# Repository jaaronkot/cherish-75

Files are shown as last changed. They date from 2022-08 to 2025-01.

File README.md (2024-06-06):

## Cherish-75

<p align="left">
  <a href="./README.md">English</a> |
  <a href="./README_CN.md">简体中文</a>
</p>

Cherish-75 is a customized mechanical keyboard featuring a Gasket structure, with its PCB already verified through prototyping.

Qmk and via support,[Source Code](https://github.com/qmk/qmk_firmware/tree/master/keyboards/soda/cherish)

## Features
* License: MIT – Free to use and modify.
* Controller: STM32F072CBT6, with a separate Type-C subboard ensuring soft elasticity.
* PCB: Slotted PCB design with optional solder mask opening (gold plating available). See [Link](https://oshwhub.com/caiyahoho/Cherish-75) for the LCSC project.
* Layout: 75% size, Fang tooth arrangement.
* Switch: Supports both soldering and hot-swappable switches.
* RGB: Features an RGB SMD LED beneath the Caps Lock key.
* Firmware: Compatible with QMK & VIA. Refer to the [fireware] directory for details.
* Case: 3D printed design with magnetic top and bottom covers. Check the [3d-model] directory for designs.

## Instructions
Magnet specifications: Diameter 3mm x thickness 2mm, available on TaoBao
Circuit board: 5 pieces, JLCPCB, 110 yuan
Components: Shaft support, chip, around 50 yuan, available on the JLCPCB online store
Positioning board: With or without slots, recommended material is FR4 or POM, 30-40 yuan per sheet, recommended store on TaoBao is "Proud Cat" for high accuracy
Place 2mm thick P foam on each pin of the PCB
3D print the casing, options include JLCPCB's 3D Monkey or Future Factory, 3D Monkey has higher accuracy but slightly higher price, the upper and lower casing would be around 150-200 yuan.

```bash
├── case-and-plate
│   ├── top-case-with-X.stl 
│   ├── top-case.stl
│   ├── bottom-case.stl
│   ├── slotted-plate.dwg
│   └── plate.dxf
├── firmware
│   ├── bin  
│   └── cherish-75-via.json # Via Config
├── hardware
│   ├── bom.xlsx # BOM
│   └── gerber # PCB  Gerber 
```

## PCB
### Black
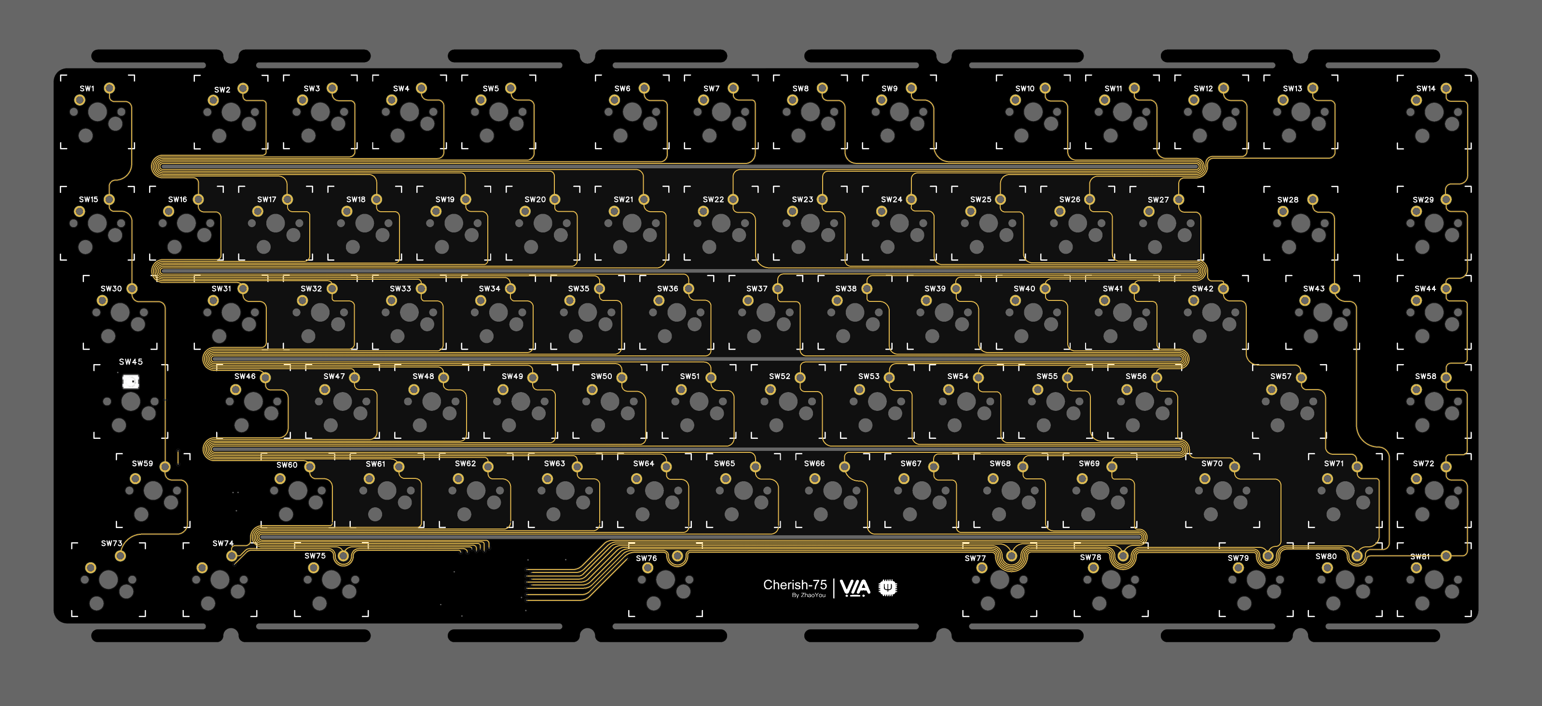
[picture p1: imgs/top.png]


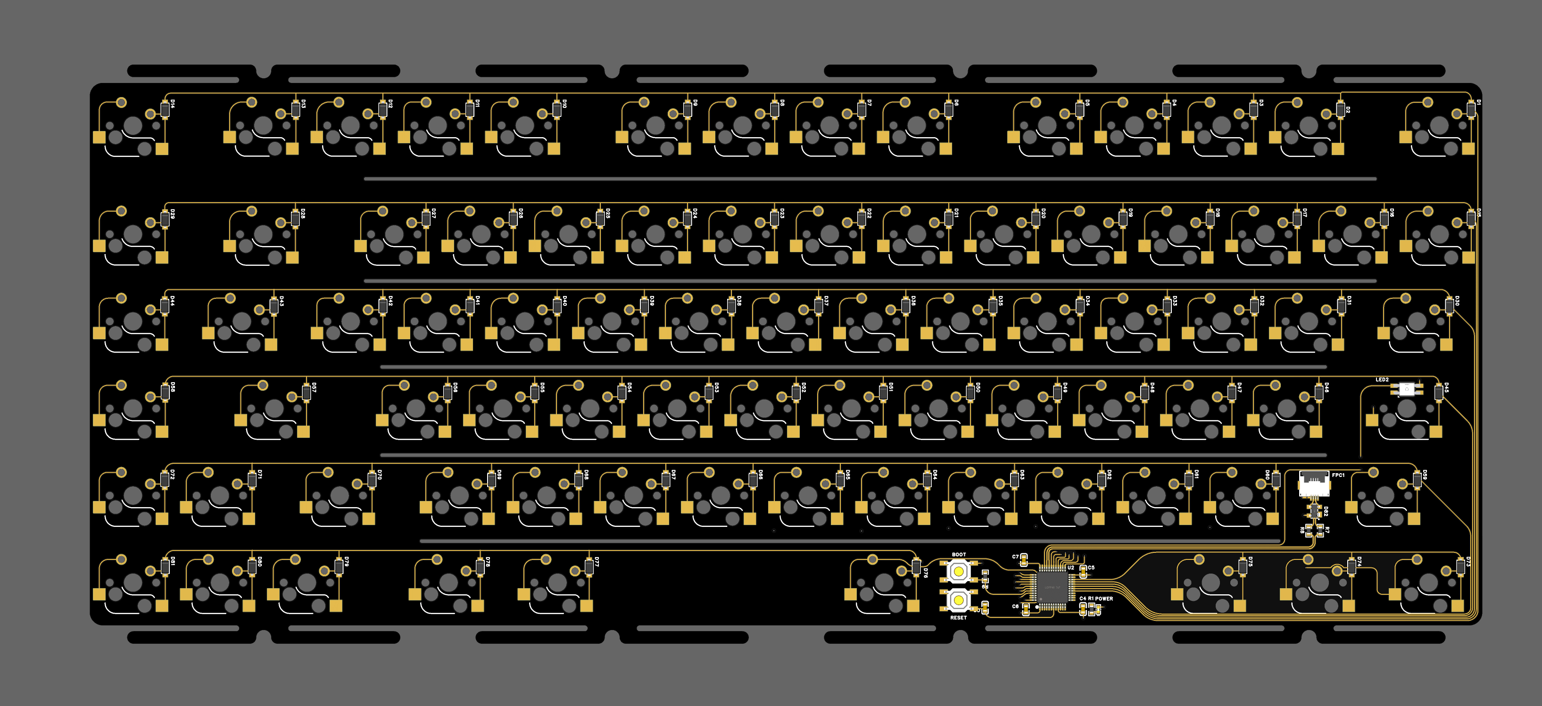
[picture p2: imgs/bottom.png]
bottom


### White:
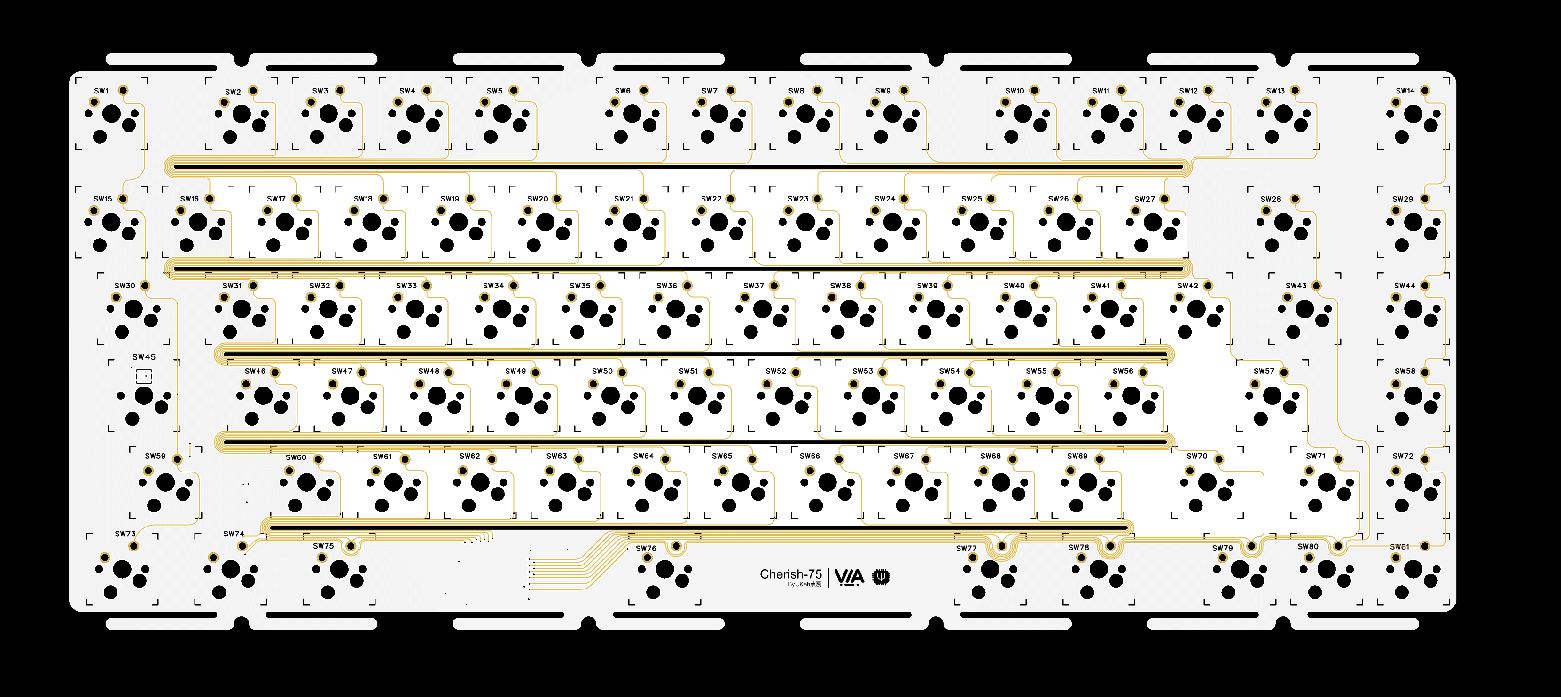
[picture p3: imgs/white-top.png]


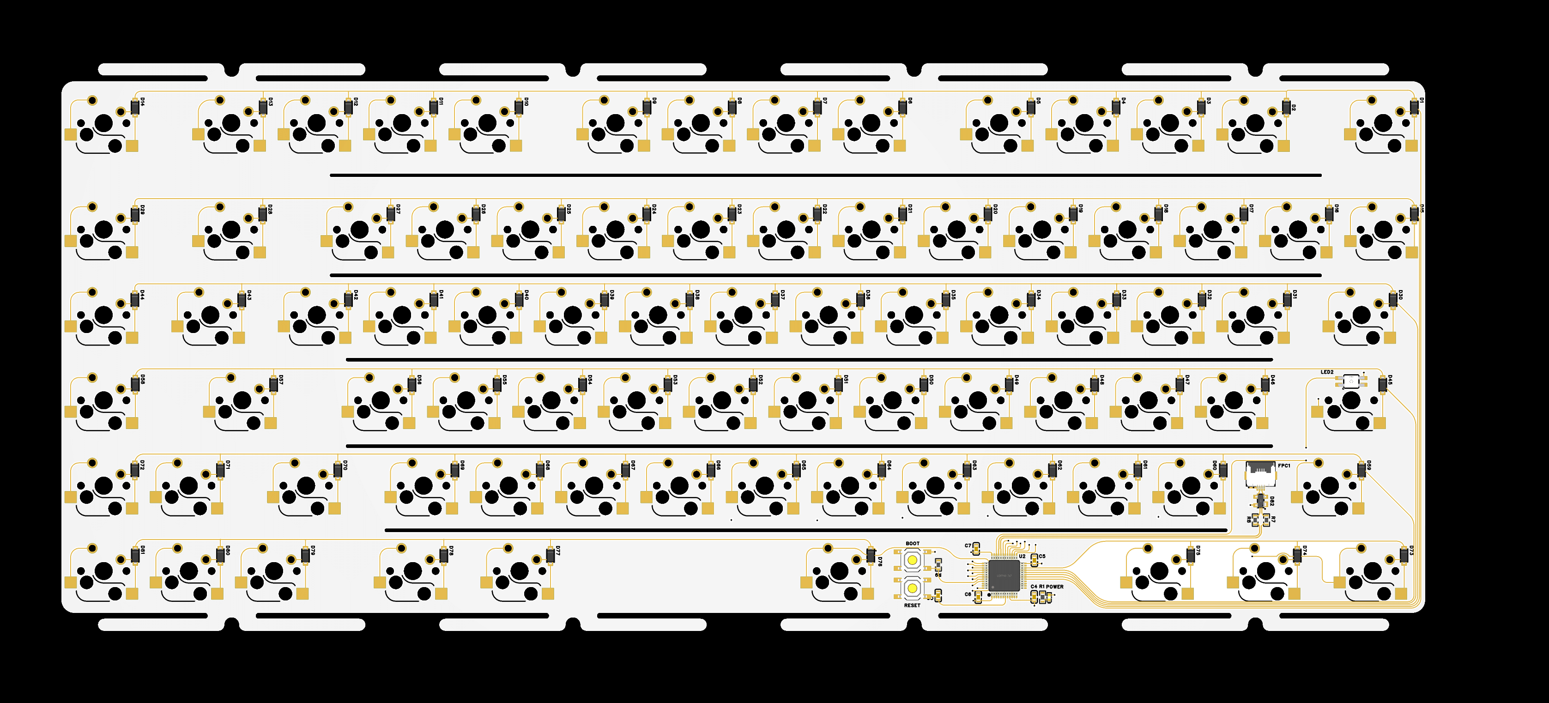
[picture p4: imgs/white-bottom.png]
bottom


### Daughterboard

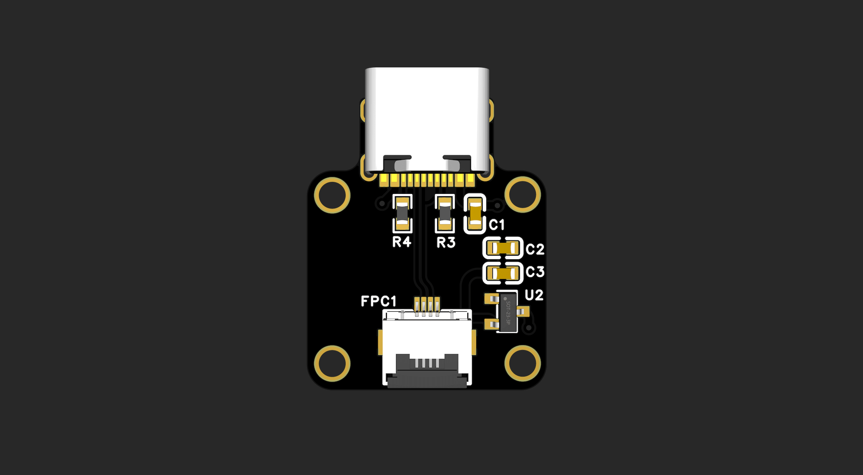
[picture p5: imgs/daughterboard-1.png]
daughterboard


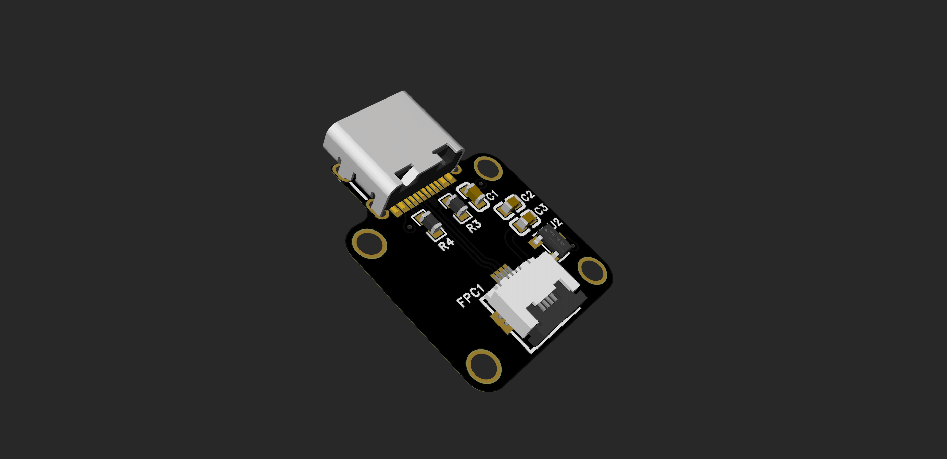
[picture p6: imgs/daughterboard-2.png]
daughterboard


## Layout

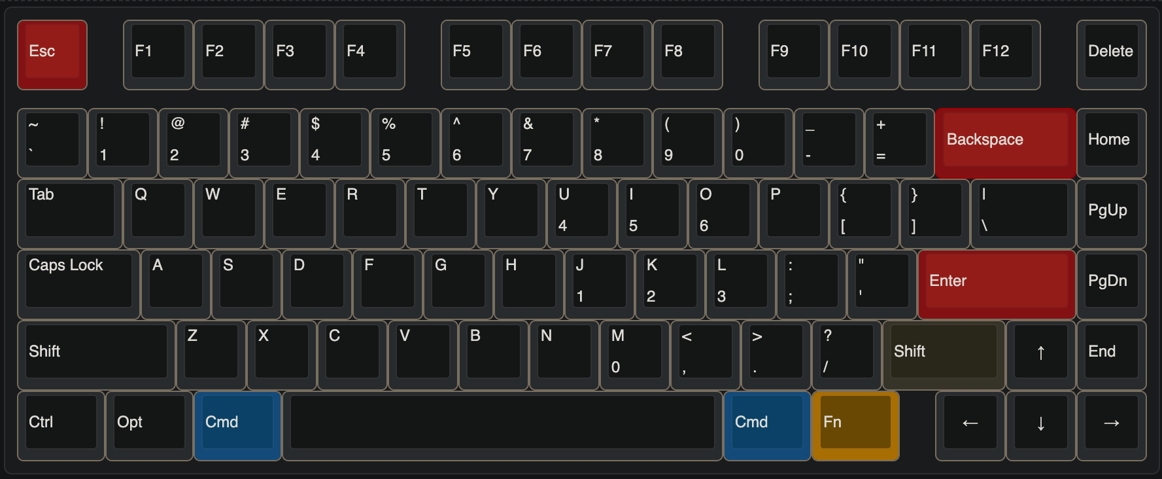
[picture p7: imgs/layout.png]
layout


**Via**
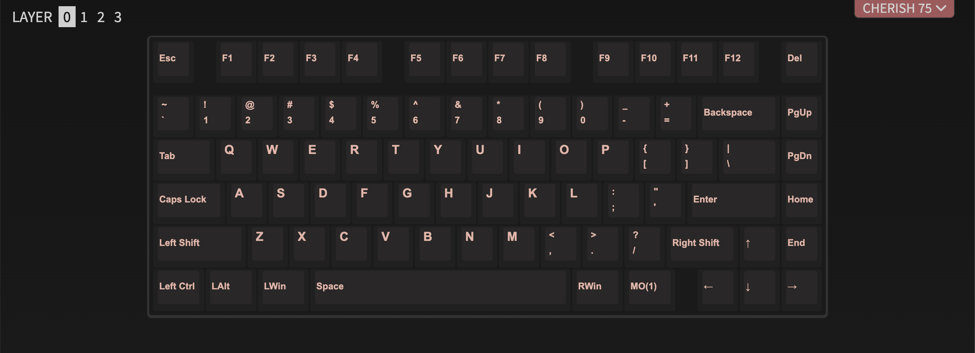
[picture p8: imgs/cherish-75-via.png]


## Case
### Top Case, Style 1

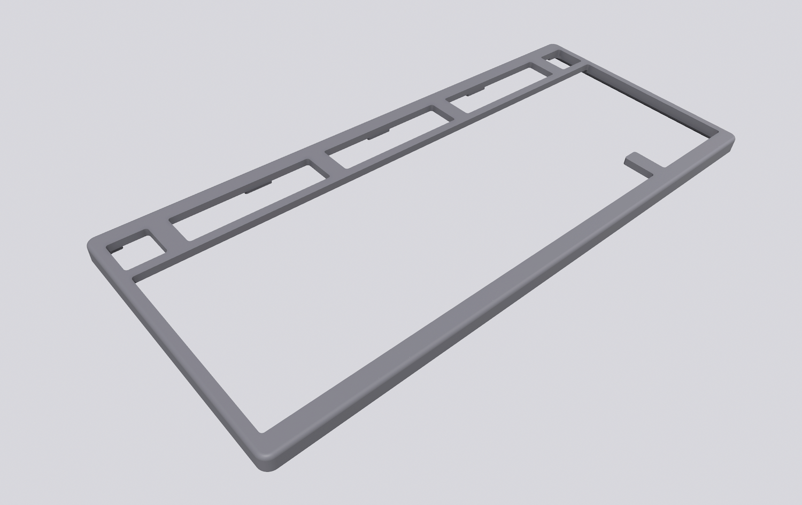
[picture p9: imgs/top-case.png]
top-case


### Top Case, Style 2

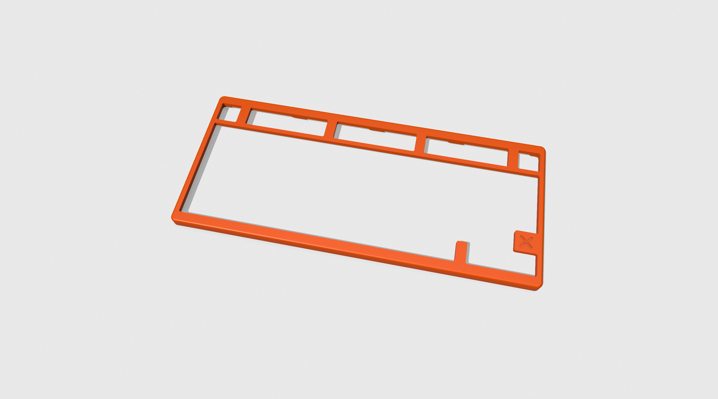
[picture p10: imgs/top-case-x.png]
top-case-x


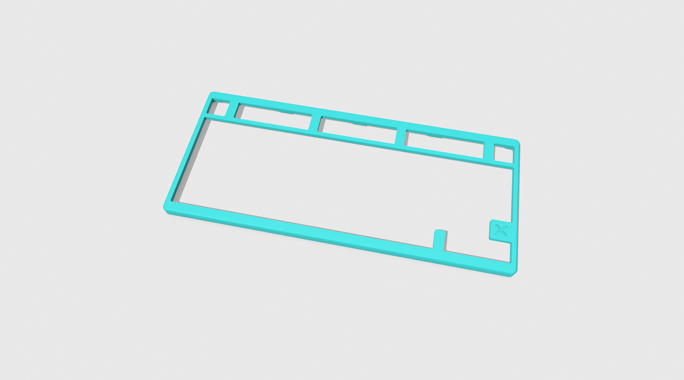
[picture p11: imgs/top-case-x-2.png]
top-case-x


### Overview

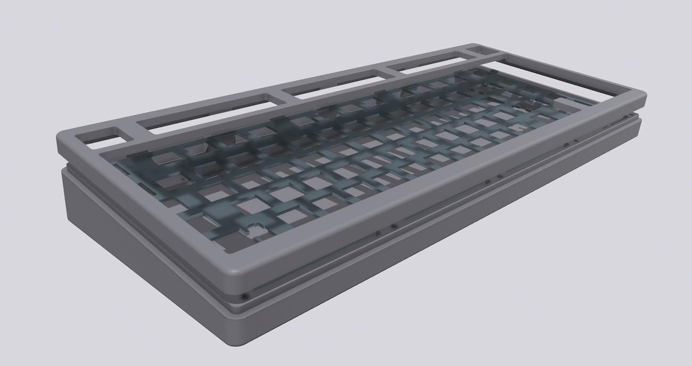
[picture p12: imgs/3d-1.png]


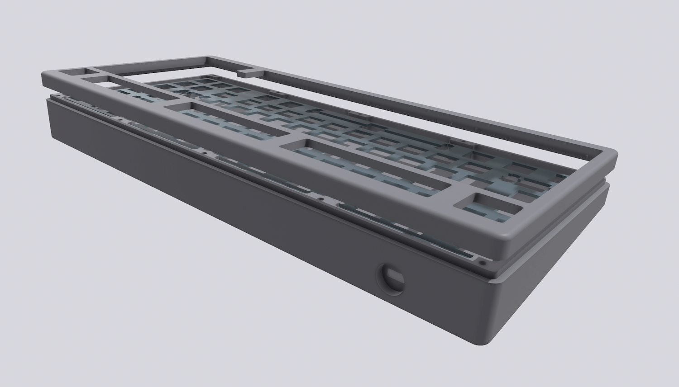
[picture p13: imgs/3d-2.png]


## Physical

### Plate

[plate-1.jpg](imgs/plate-1.jpg)

### PCB 

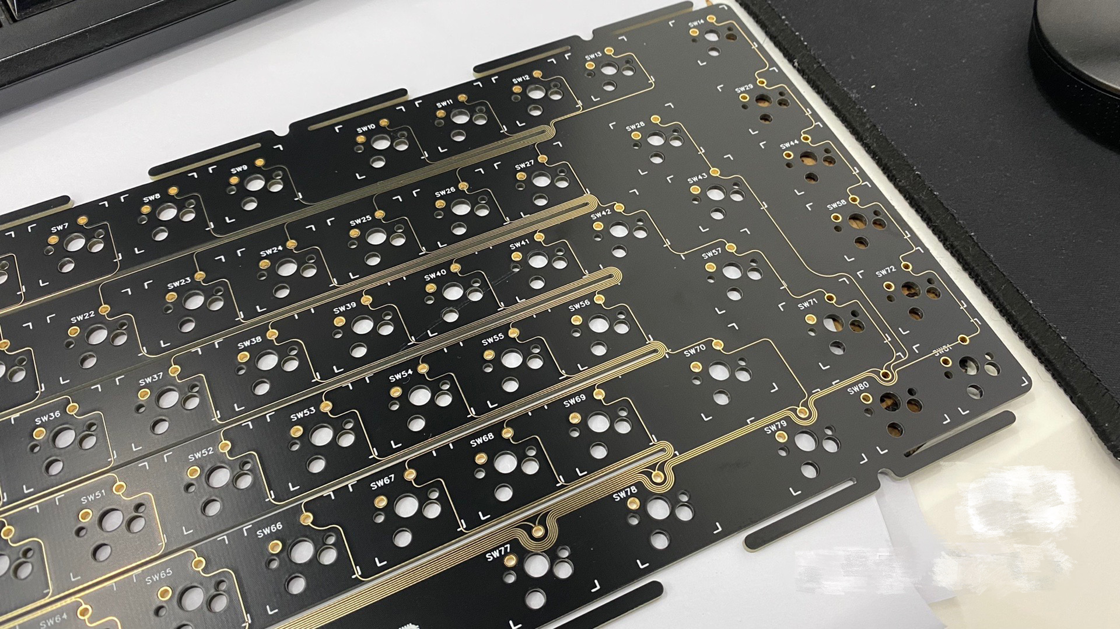
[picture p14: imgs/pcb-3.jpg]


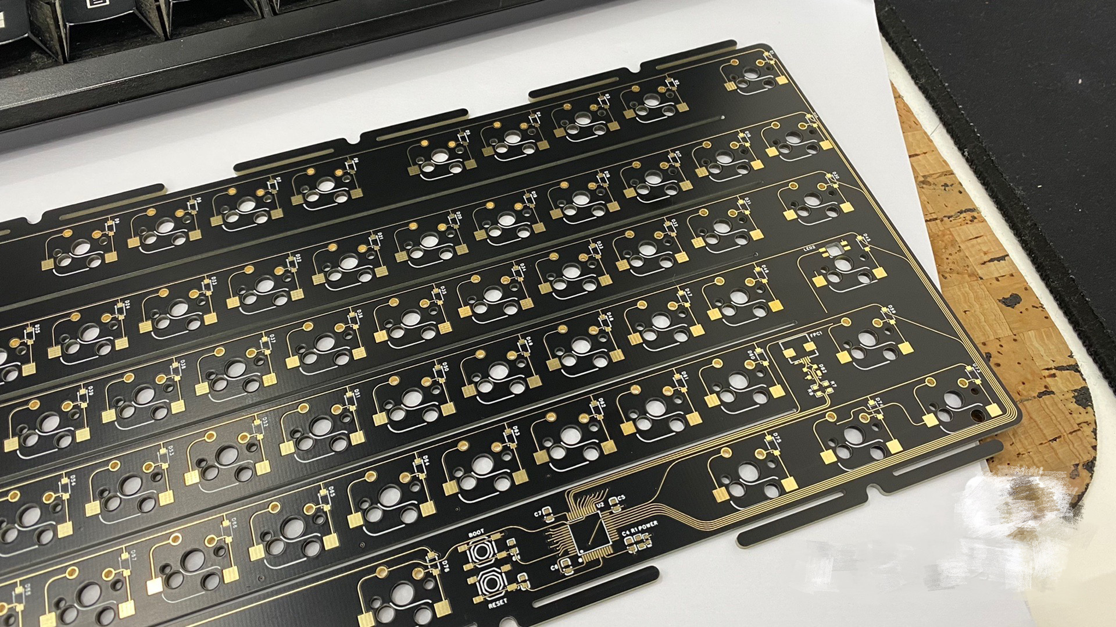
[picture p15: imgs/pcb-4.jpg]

 
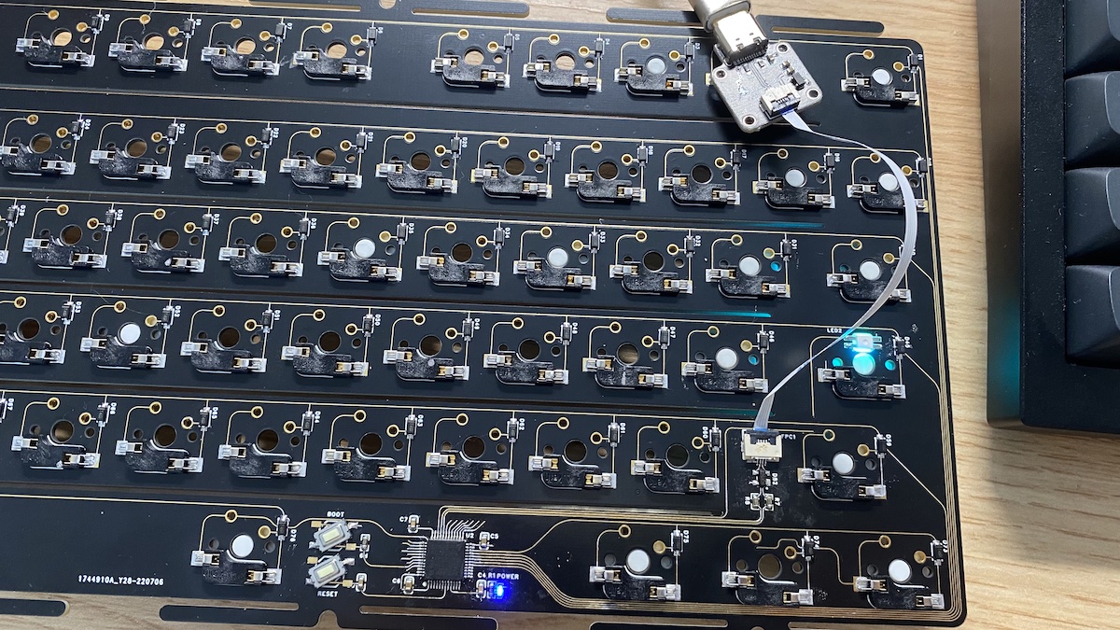
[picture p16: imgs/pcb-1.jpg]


### Keyboard
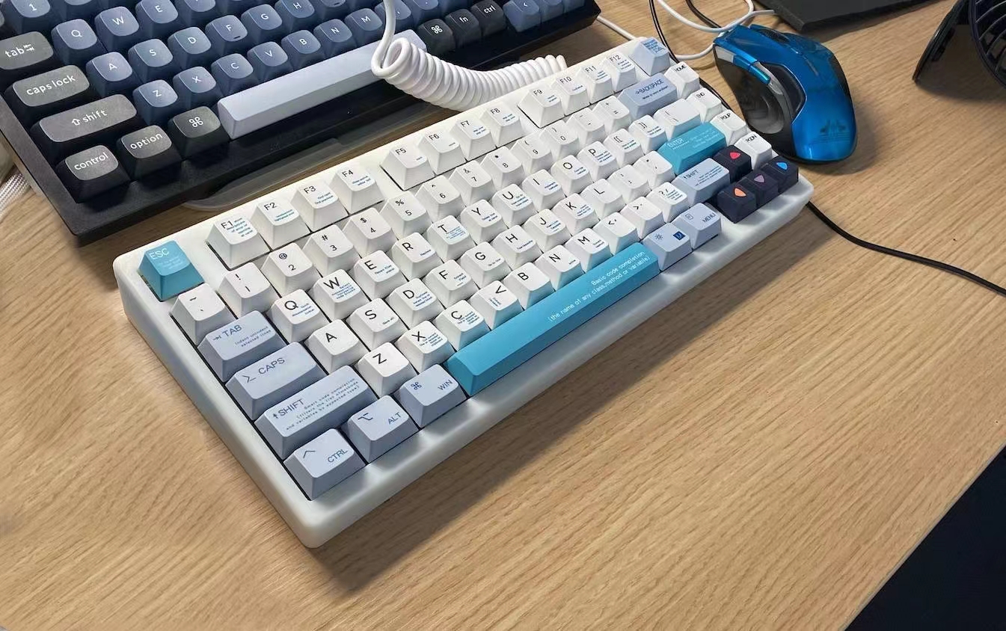
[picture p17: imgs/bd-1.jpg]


### Video
**BiliBili**

bilibili (https://www.bilibili.com/video/BV1CS4y1W7Da/)
 
**Youtube**
Cherish-75 (https://www.youtube.com/watch?v=ES9FB7N3KS8&t=7s "Cherish-75")

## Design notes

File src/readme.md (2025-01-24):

# CHERISH-75

A customizable 75%  keyboard, support both HOTSWAP and SOLDER.

* Keyboard Maintainer: [gezhaoyou](https://github.com/gezhaoyou)
* Hardware Supported: [gezhaoyou](https://github.com/gezhaoyou)
* Hardware Availability: [Cherish-75](https://github.com/gezhaoyou/Cherish-75)

Make example for this keyboard (after setting up your build environment):

**default**:

```shell
qmk compile -kb soda/cherish -km default
```

**via:**

```shell
qmk compile -kb soda/cherish -km via
```

## Bootloader

Enter the bootloader in 2 ways:

* **Physical reset button**: Briefly press the button: [boot] first, then press button: [reset]  on the back of the PCB
* **Keycode in layout**: Press the key mapped to `QK_BOOT` if it is available

See the [build environment setup](https://docs.qmk.fm/#/getting_started_build_tools) and the [make instructions](https://docs.qmk.fm/#/getting_started_make_guide) for more information. Brand new to QMK? Start with our [Complete Newbs Guide](https://docs.qmk.fm/#/newbs).

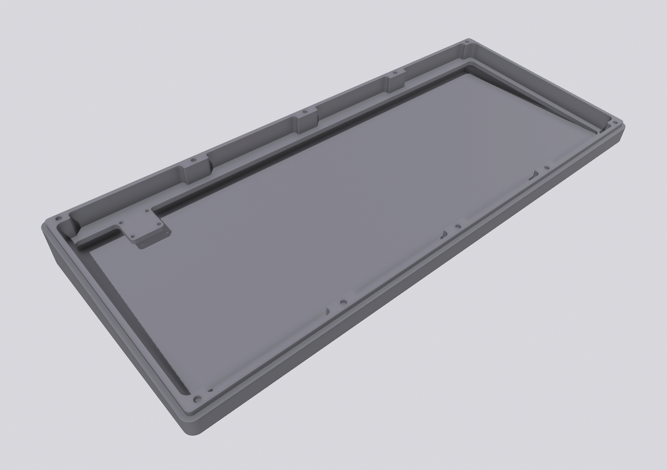
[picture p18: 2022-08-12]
imgs/bottom-case.png

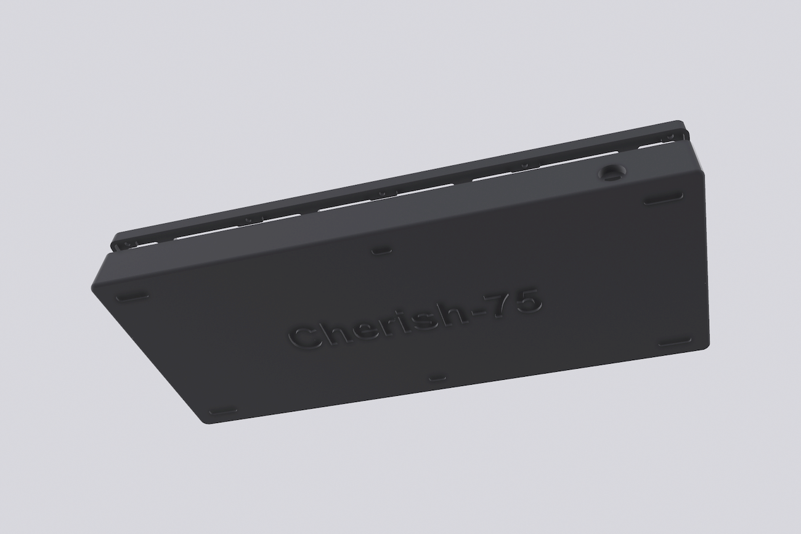
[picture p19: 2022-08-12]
imgs/3d-3.png

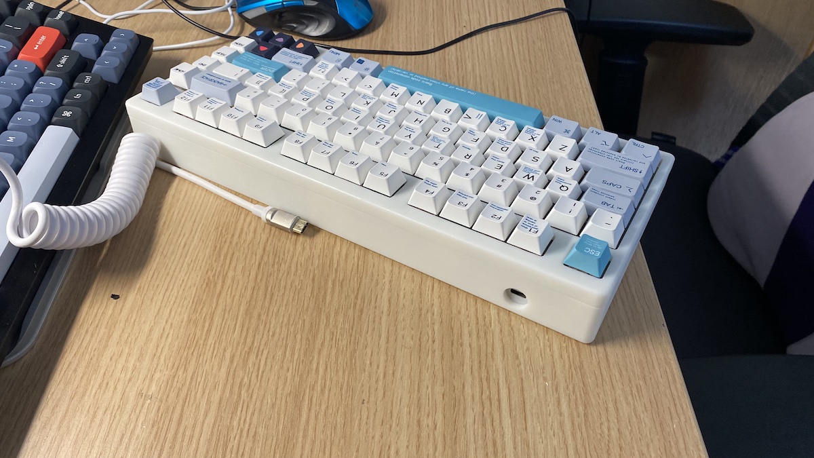
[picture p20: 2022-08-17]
imgs/bd-2.jpg

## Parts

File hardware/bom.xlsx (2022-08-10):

No. | Quantity | Device | Designator | Footprint | Value | Manufacturer Part | Manufacturer | Supplier Part | Supplier
1 | 2 | TS-1187A-B-B-B | BOOT,RESET | SW-SMD_4P-L5.1-W5.1-P3.70-LS6.5-TL-2 |  | TS-1187A-B-B-B | XKB Connectivity(中国星坤) | C528026 | LCSC
2 | 5 | CC0603KRX7R9BB104 | C4,C5,C6,C7,C8 | C0603 | 100nF | CC0603KRX7R9BB104 | YAGEO(国巨) | C14663 | LCSC
3 | 81 | 1N4148W_C115103 | D1,D2,D3,D4,D5,D6,D7,D8,D9,D10,D11,D12,D13,D14,D15,D16,D17,D18,D19,D20,D21,D22,D23,D24,D25,D26,D27,D28,D29,D30,D31,D32,D33,D34,D35,D36,D37,D38,D39,D40,D41,D42,D43,D44,D45,D46,D47,D48,D49,D50,D51,D52,D53,D54,D55,D56,D57,D58,D59,D60,D61,D62,D63,D64,D65,D66,D67,D68,D69,D70,D71,D72,D73,D74,D75,D76,D77,D78,D79,D80,D81 | SOD-123_L2.8-W1.8-LS3.7-RD |  | 1N4148W | 晶导微电子 | C115103 | LCSC
4 | 1 | PRTR5V0U2X_C2827688 | D82 | SOT-143-4_L2.9-W1.3-P1.92-LS2.4-BL |  | PRTR5V0U2X | TECH PUBLIC(台舟) | C2827688 | LCSC
5 | 1 | AFC01-S04FCC-00 | FPC1 | FFC-SMD_4P-P0.50_AFC01-S04FCC-00 |  | AFC01-S04FCC-00 | JS(钜硕电子) | C262260 | LCSC
6 | 1 | DY-S352818/RGBC/6812-2T | LED2 | LED-SMD_L3.2-W2.8-BR_DY-S352818 |  | DY-S352818/RGBC/6812-2T | TONYU(东裕) | C524051 | LCSC
7 | 1 | TJ-S1005SW4TGLC6B-A5 | POWER | LED0402-RD_BLUE |  | TJ-S1005SW4TGLC6B-A5 | TOGIALED(台湾统佳) | C273603 | LCSC
8 | 1 | CR0603F1K00P05Z | R1 | R0603 | 1kΩ | CR0603F1K00P05Z | EVER OHMS(天二科技) | C881323 | LCSC
9 | 2 | MR06X220JTL | R7,R8 | R0603 | 22 | MR06X220JTL | 华新科(Walsin) | C327833 | LCSC
10 | 1 | ERJ3EKF1002V | R9 | R0603 | 10kΩ | ERJ3EKF1002V | PANASONIC(松下) | C191124 | LCSC
11 | 80 | Kailh-Switch | SW1,SW2,SW3,SW4,SW5,SW6,SW7,SW8,SW9,SW10,SW11,SW12,SW13,SW14,SW15,SW16,SW17,SW18,SW19,SW20,SW21,SW22,SW23,SW24,SW25,SW26,SW27,SW28,SW29,SW30,SW31,SW32,SW33,SW34,SW35,SW36,SW37,SW38,SW39,SW40,SW41,SW42,SW43,SW44,SW46,SW47,SW48,SW49,SW50,SW51,SW52,SW53,SW54,SW55,SW56,SW57,SW58,SW59,SW60,SW61,SW62,SW63,SW64,SW65,SW66,SW67,SW68,SW69,SW70,SW71,SW72,SW73,SW74,SW75,SW76,SW77,SW78,SW79,SW80,SW81 | Kailh_Switch_MX_Optional
13 | 1 | STM32F072C8T6 | U2 | LQFP-48_L7.0-W7.0-P0.50-LS9.0-BL |  | STM32F072C8T6 | ST(意法半导体) | C80488 | LCSC

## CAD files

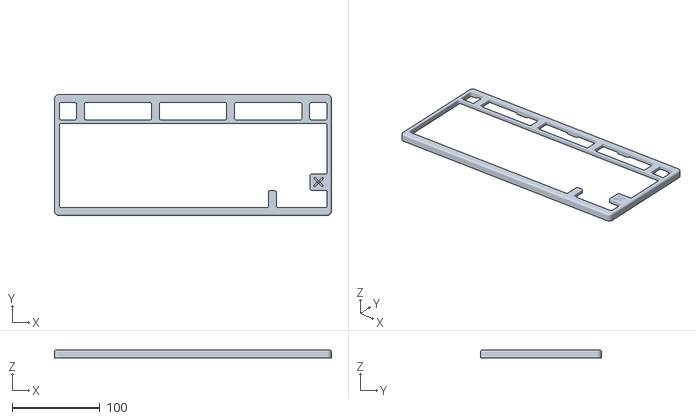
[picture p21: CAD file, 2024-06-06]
case-and-plate/top-case-with-X.stl
316.0 x 138.2 x 9.00

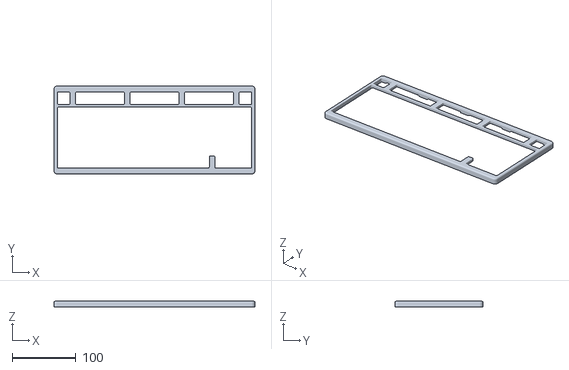
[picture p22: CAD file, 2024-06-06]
case-and-plate/top-case.stl
316.0 x 138.2 x 9.00

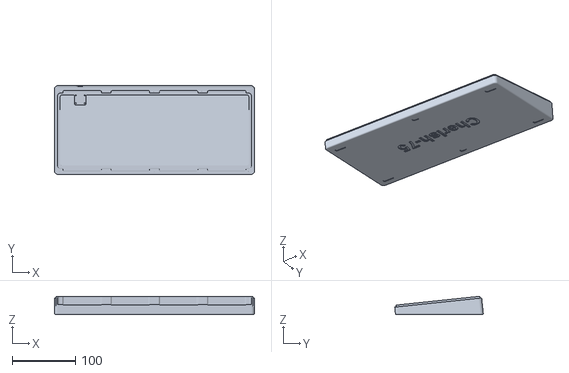
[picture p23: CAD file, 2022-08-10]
case-and-plate/bottom-case.stl
316.0 x 140.0 x 29.1

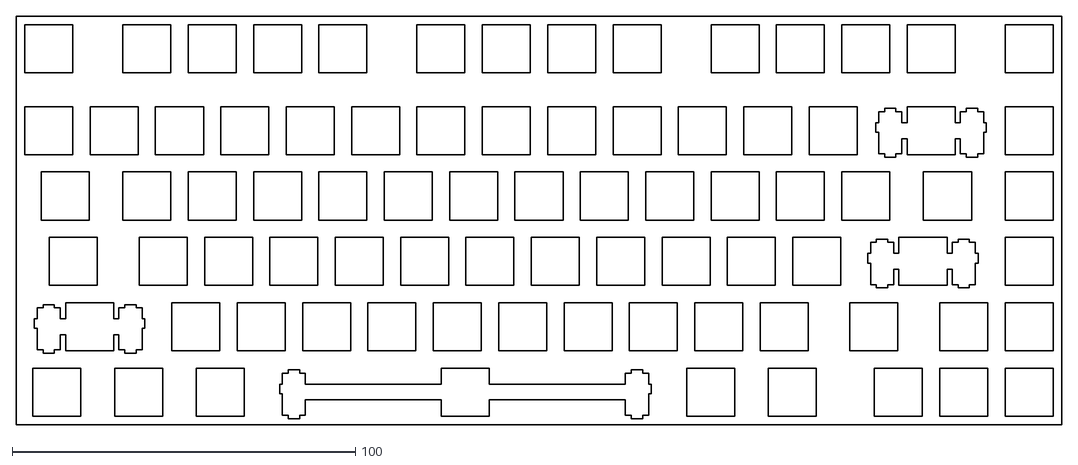
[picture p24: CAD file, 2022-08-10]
case-and-plate/plate.dxf
304.8 x 119.1

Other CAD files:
case-and-plate/slotted-plate.dwg

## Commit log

2022-06-17 init: upload file
    [TP75.kicad_sch]
2022-08-09 add pcb link and qmk fireware
    [TP75.kicad_sch]
2022-08-10 添加定位板，3D打印文件，PCB BOM
    [Cherish-75-上壳.stl, Cherish-75-下壳.stl, bom.xlsx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]
2022-08-11 add gerber and case
2022-08-11 增加定位板和外壳模型文件
    [Cherish-75-定位板.stl]
2022-08-17 添加打样效果和组装实体
2022-08-25 update 上壳
    [Cherish-75-上壳.stl]
2022-08-28 add daughter board
2022-11-20 更新3D打印上壳文件，调整键帽与壳距离
    [Cherish-75-上壳.stl]
2023-05-10 readme添加星球和Q群
